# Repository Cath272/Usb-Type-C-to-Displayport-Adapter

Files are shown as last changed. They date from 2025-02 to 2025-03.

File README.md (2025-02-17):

# Usb Type C to Displayport Adapter
 Usb Type C (DP Alt Mode)  to Displayport Adapter
 4 DP lanes

 Simple Usb C to Displayport Adapter using the VL100-Q3/VL103-Q3 ic
 VL103-Q3 does not need external crystal but VL100-Q3 can be found cheaper 

 The design is not final!

 ## VL100-Q3/VL103-Q3

  - CC Logic & PD 3.0 Engine 

  - Compliant to VESA DisplayPort Alt Mode on USB Type C Standard Version 1.0 a

  - USB Billboard Device

  ###  Built-in Voltage Regulators

- 5.0V to 3.3V LDO

- 3.3V to 1.8V LDO

## PCB 
This board uses a 4 layer stackup with a  1.6mm thickness:

- POWER/SIGNAL

- GND
  
- GND
  
- POWER/SIGNAL

High Speed diferential lines need a refrence ground plane so internal planes are ground referance planes for the High speed USB lines

### Schematic:
Schematic

## PCB Screenshots

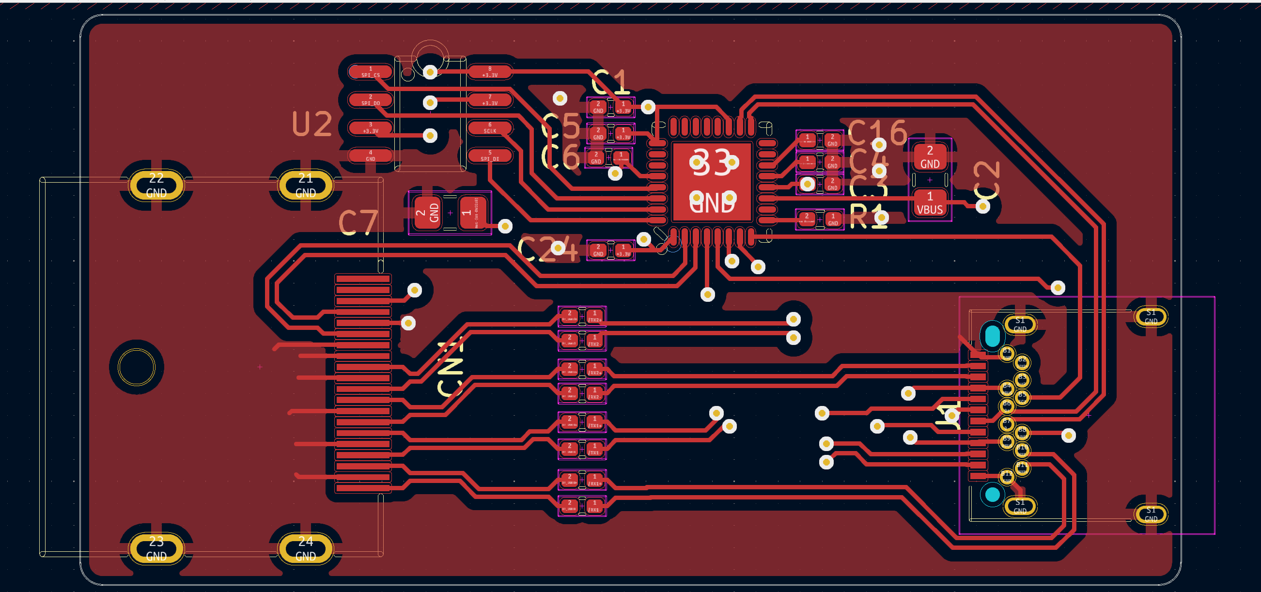
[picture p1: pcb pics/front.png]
usb3satafront

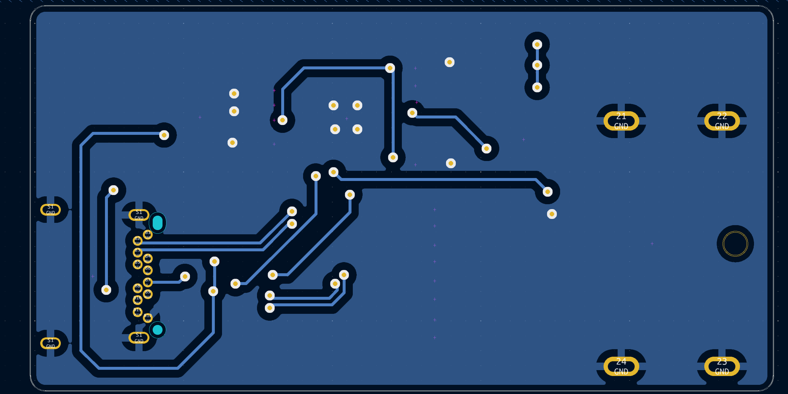
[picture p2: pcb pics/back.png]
usb3sataback

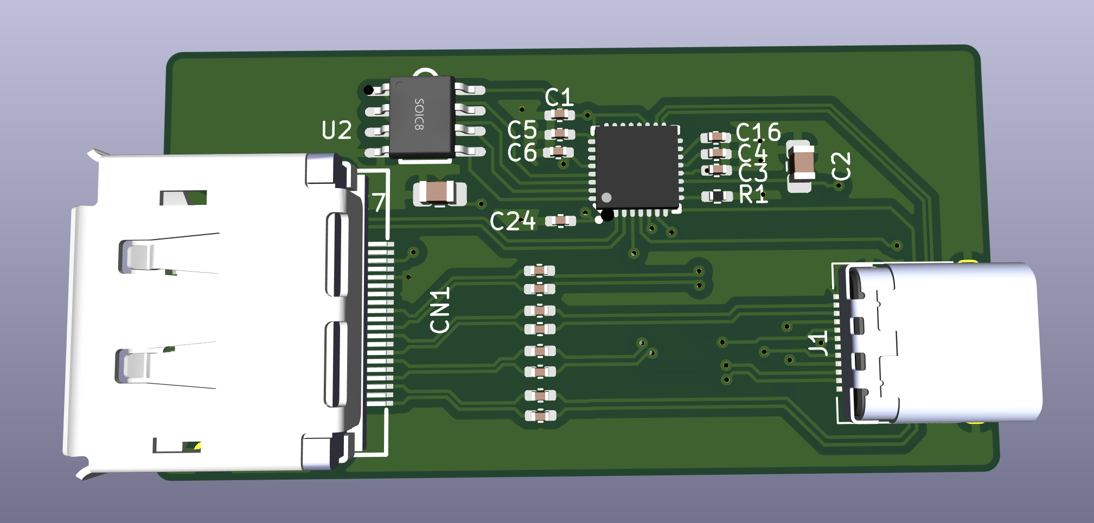
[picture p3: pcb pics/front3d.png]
usb3satafront3d

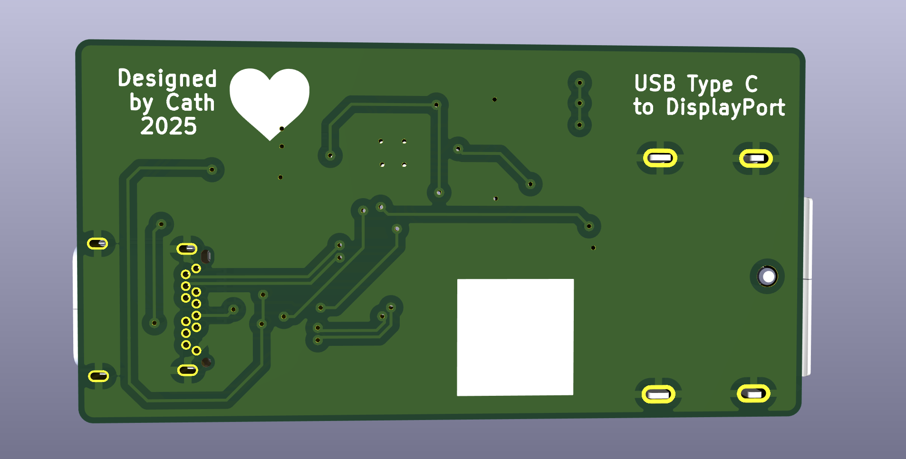
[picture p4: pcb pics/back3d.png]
usb3sataback3d


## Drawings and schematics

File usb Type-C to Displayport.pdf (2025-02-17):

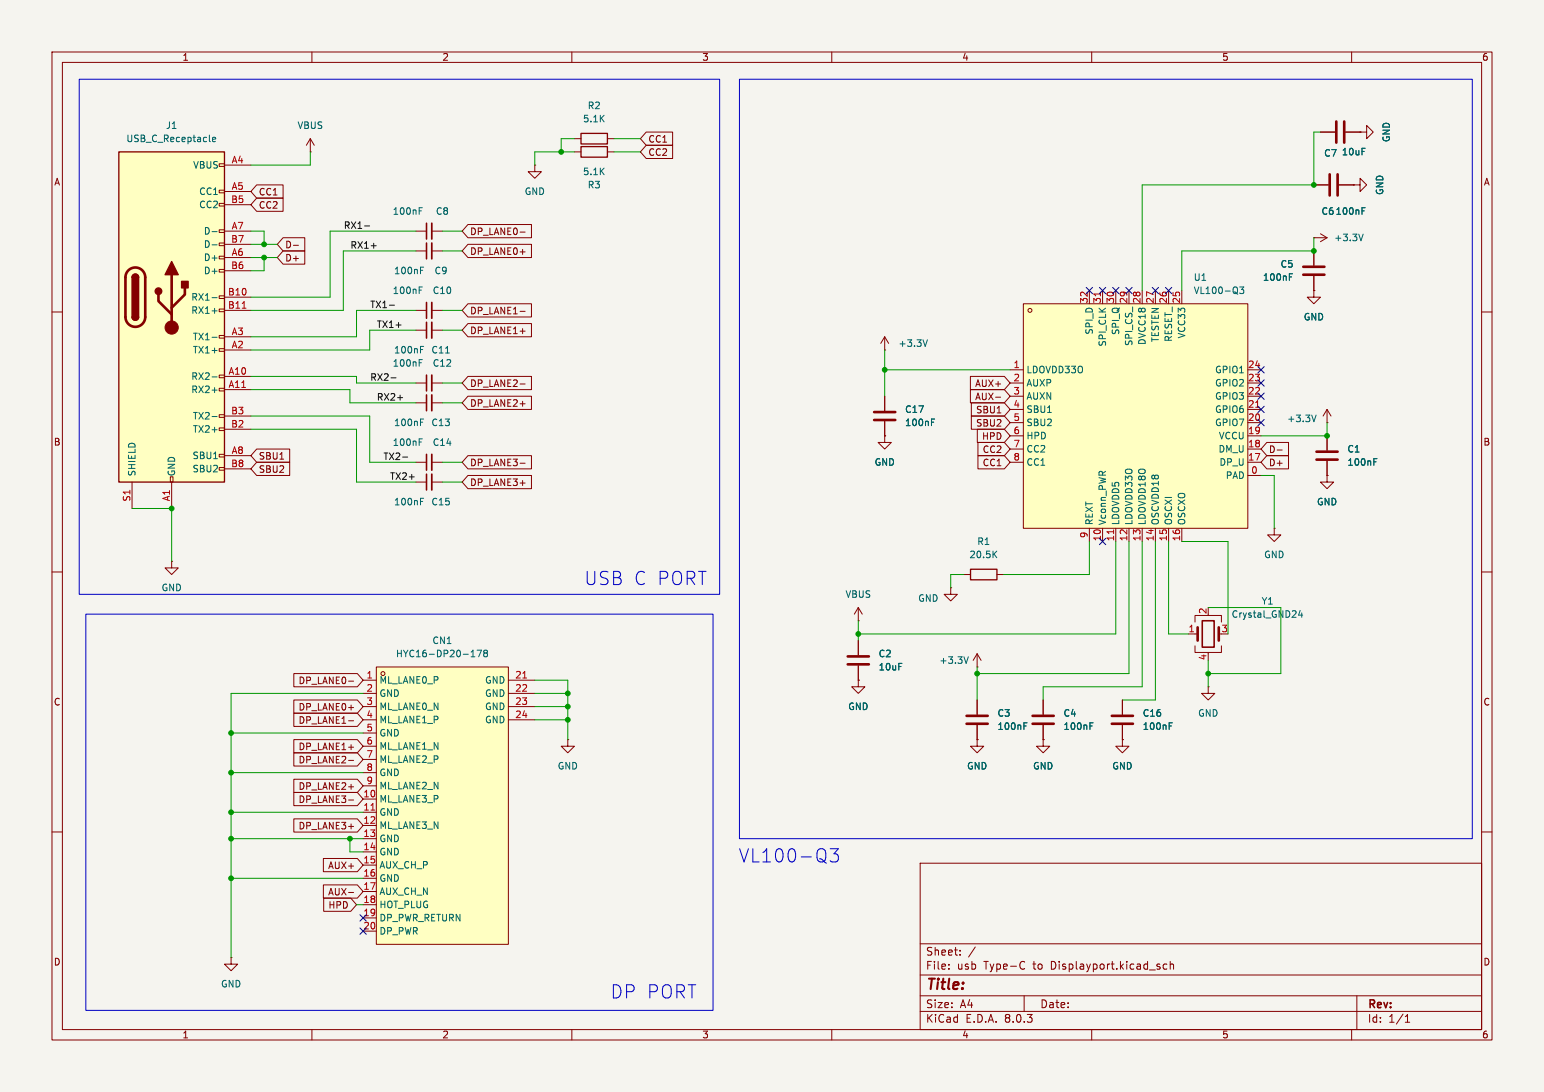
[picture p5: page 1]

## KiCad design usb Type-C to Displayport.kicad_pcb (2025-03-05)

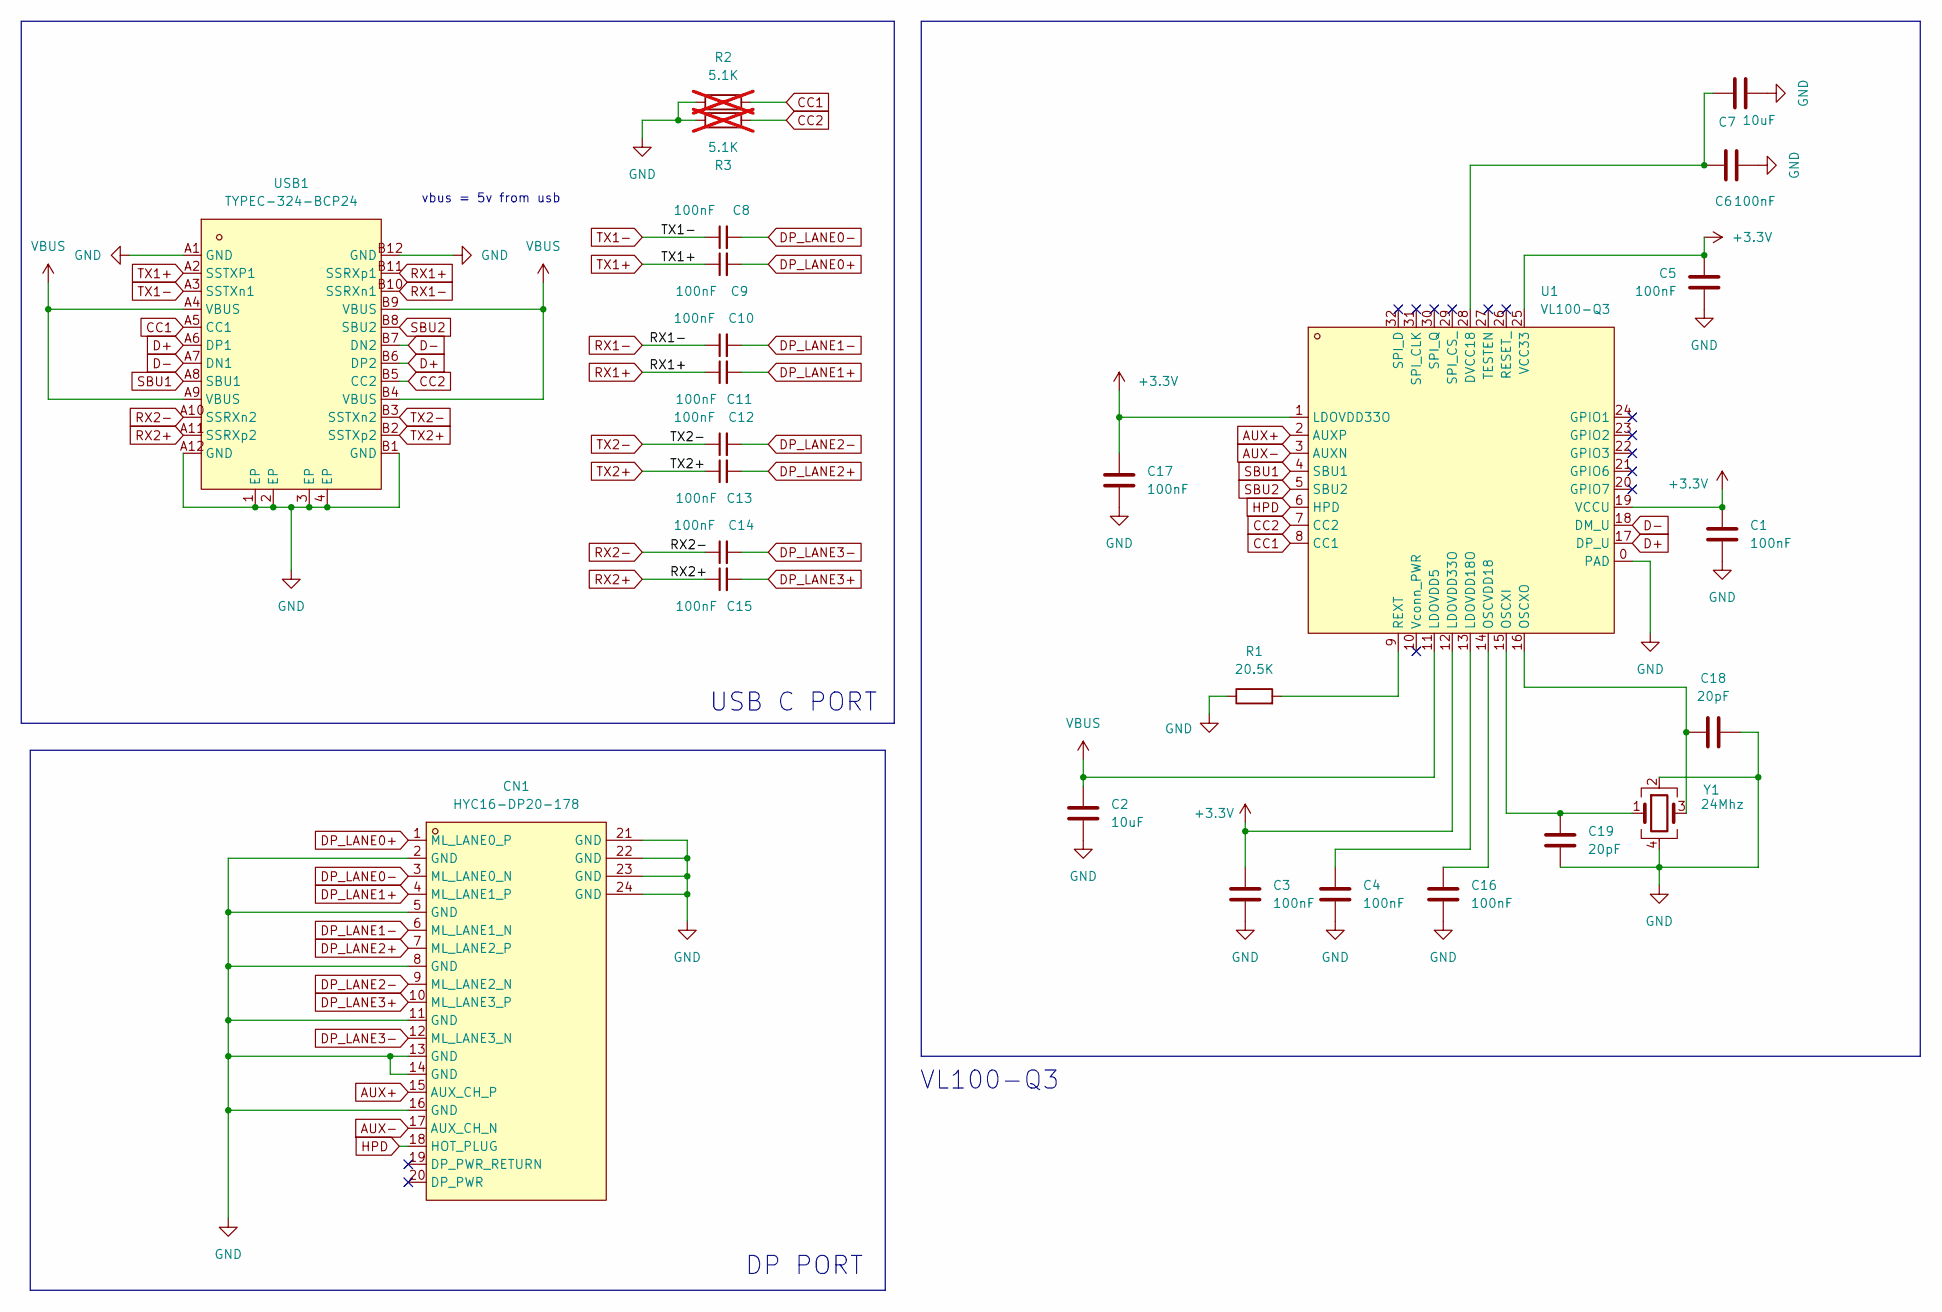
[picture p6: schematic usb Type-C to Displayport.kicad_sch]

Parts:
C1, C3, C4, C5, C6, C8, C9, C10, C11, C12, C13, C14, C15, C16, C17: 100nF; C_0402_1005Metric_Pad0.74x0.62mm_HandSolder
C2, C7: 10uF; C_0805_2012Metric_Pad1.18x1.45mm_HandSolder
C18, C19: 20pF; C_0402_1005Metric
CN1: HYC16-DP20-178; DP-SMD_HYC16-DP20-178; LCSC Part C711350
R1: 20.5K; R_0402_1005Metric_Pad0.72x0.64mm_HandSolder
R2, R3: 5.1K; R_0402_1005Metric; not fitted
U1: VL100-Q3; QFN-32_L5.0-W5.0-P0.50-BL-EP3.4; LCSC Part C69731
USB1: TYPEC-324-BCP24; USB-C-SMD_TYPEC-324-BCP24; LCSC Part C2835314
Y1: 24Mhz; Crystal_SMD_3225-4Pin_3.2x2.5mm

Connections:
+3.3V: C1.1, C3.1, C5.1, C17.1, U1.1 (LDOVDD33O), U1.12 (LDOVDD33O), U1.19 (VCCU), U1.25 (VCC33)
AUX+: CN1.15 (AUX_CH_P), U1.2 (AUXP)
AUX-: CN1.17 (AUX_CH_N), U1.3 (AUXN)
CC1: R2.1, U1.8 (CC1), USB1.A5 (CC1)
CC2: R3.1, U1.7 (CC2), USB1.B5 (CC2)
D+: U1.17 (DP_U), USB1.A6 (DP1), USB1.B6 (DP2)
D-: U1.18 (DM_U), USB1.A7 (DN1), USB1.B7 (DN2)
DP_LANE0+: C9.2, CN1.1 (ML_LANE0_P)
DP_LANE0-: C8.2, CN1.3 (ML_LANE0_N)
DP_LANE1+: C11.2, CN1.4 (ML_LANE1_P)
DP_LANE1-: C10.2, CN1.6 (ML_LANE1_N)
DP_LANE2+: C13.2, CN1.7 (ML_LANE2_P)
DP_LANE2-: C12.2, CN1.9 (ML_LANE2_N)
DP_LANE3+: C15.2, CN1.10 (ML_LANE3_P)
DP_LANE3-: C14.2, CN1.12 (ML_LANE3_N)
GND: C1.2, C2.2, C3.2, C4.2, C5.2, C6.2, C7.2, C16.2, C17.2, C18.2, C19.1, CN1.2 (GND), CN1.5 (GND), CN1.8 (GND), CN1.11 (GND), CN1.13 (GND), CN1.14 (GND), CN1.16 (GND), CN1.21 (GND), CN1.22 (GND), CN1.23 (GND), CN1.24 (GND), R1.1, R2.2, R3.2, U1.0 (PAD), USB1.1 (EP), USB1.2 (EP), USB1.3 (EP), USB1.4 (EP), USB1.A1 (GND), USB1.A12 (GND), USB1.B1 (GND), USB1.B12 (GND), Y1.2, Y1.4
HPD: CN1.18 (HOT_PLUG), U1.6 (HPD)
unnamed: C6.1, C7.1, U1.28 (DVCC18)
unnamed: C4.1, U1.13 (LDOVDD18O)
unnamed: C16.1, U1.14 (OSCVDD18)
unnamed: C19.2, U1.15 (OSCXI), Y1.1
unnamed: C18.1, U1.16 (OSCXO), Y1.3
unnamed: R1.2, U1.9 (REXT)
RX1+: C11.1, USB1.B11 (SSRXp1)
RX1-: C10.1, USB1.B10 (SSRXn1)
RX2+: C15.1, USB1.A11 (SSRXp2)
RX2-: C14.1, USB1.A10 (SSRXn2)
SBU1: U1.4 (SBU1), USB1.A8 (SBU1)
SBU2: U1.5 (SBU2), USB1.B8 (SBU2)
TX1+: C9.1, USB1.A2 (SSTXP1)
TX1-: C8.1, USB1.A3 (SSTXn1)
TX2+: C13.1, USB1.B2 (SSTXp2)
TX2-: C12.1, USB1.B3 (SSTXn2)
VBUS: C2.1, U1.11 (LDOVDD5), USB1.A4 (VBUS), USB1.A9 (VBUS), USB1.B4 (VBUS), USB1.B9 (VBUS)

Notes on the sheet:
vbus = 5v from usb
USB C PORT
VL100-Q3
DP PORT

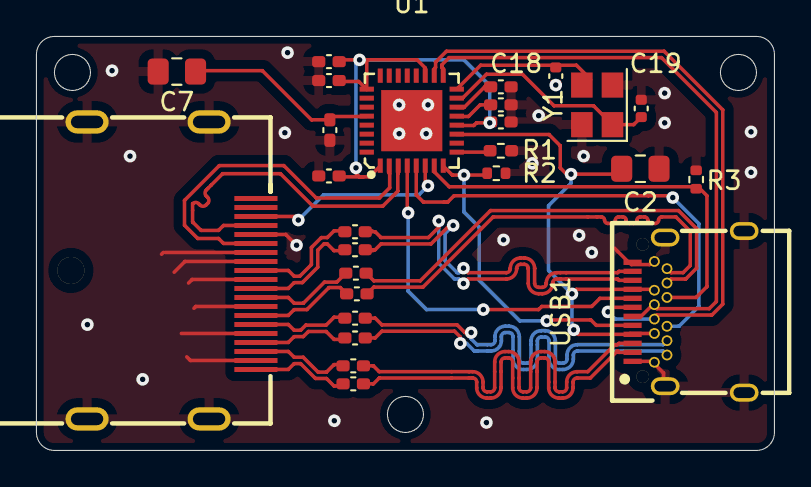
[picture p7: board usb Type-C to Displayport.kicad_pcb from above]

Board: 4 copper layers, 41.0 x 23.0 mm, 26 parts (0 on the bottom side), 34 nets.

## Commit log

2025-02-07 Initial Release
    Uploaded Board, schematic and pics
    [usb Type-C to Displayport.kicad_pcb, usb Type-C to Displayport.kicad_sch]
2025-02-09 0.2
    Removed SPI chip, fixed CC lines being reversed, made pcb smaller, added mounting holes
    [usb Type-C to Displayport.kicad_pcb, usb Type-C to Displayport.kicad_sch]
2025-02-17 Changed IC to vl100 q3
    Changed ic to vl100 q3 (i found it cheaper and it's pin compatible, added Crystal)
    [usb Type-C to Displayport.kicad_pcb, usb Type-C to Displayport.kicad_sch]
2025-02-21 Fixed usb footprint
    [usb Type-C to Displayport.kicad_pcb, usb Type-C to Displayport.kicad_sch]
2025-02-22 Fixed DP lines
    Fixed wrong USB lines to DP lines, fixed differential pairs not length matched, length matched all 4 pairs
    [usb Type-C to Displayport.kicad_pcb, usb Type-C to Displayport.kicad_sch]
